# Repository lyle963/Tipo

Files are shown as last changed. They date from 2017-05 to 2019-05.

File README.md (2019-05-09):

# Tipo
Plug n Play Braille Keyboard for your smartphone

# What is available?
1. Arduino Firmware for a USB keyboard using atmega32u4
2. Eagle CAD board files to print the PCB

# TO-DO
1. Remove bt ezkey module and get the arduino micro to type stuff onto notepad using 2 or 3 buttons - Done

2. Repeat with USBOTG and make sure phone responds - Done

3. Connect 8 keys to micro on breadboard in matrix or parallel layout to verify all peri electronics - Done

4. Dump Leonardo bootloader to wild Atmega32u4 Chip - Done

5. Breadboard standalone chip with external oscillator,caps,resistors etc - Skipped like a bawz

6. Design / Fab pcb and test with phone - Done

7. CAD Case

8. Print case

9. Give board to visually impared peeps & get feedback

10. Brailler Trainer app

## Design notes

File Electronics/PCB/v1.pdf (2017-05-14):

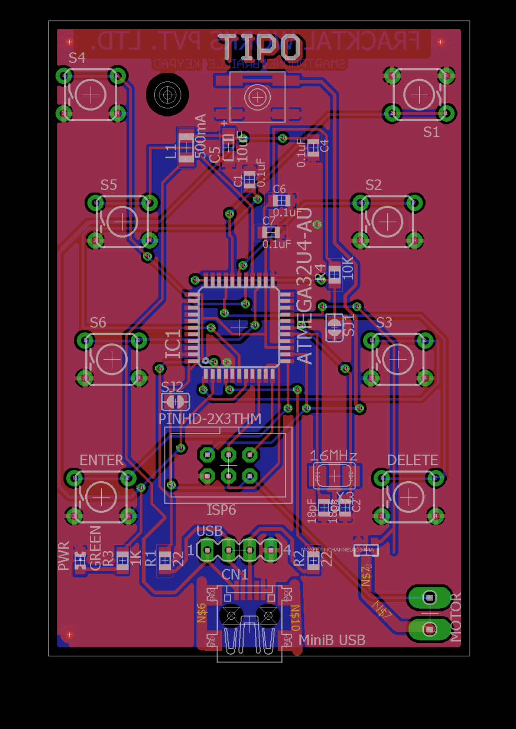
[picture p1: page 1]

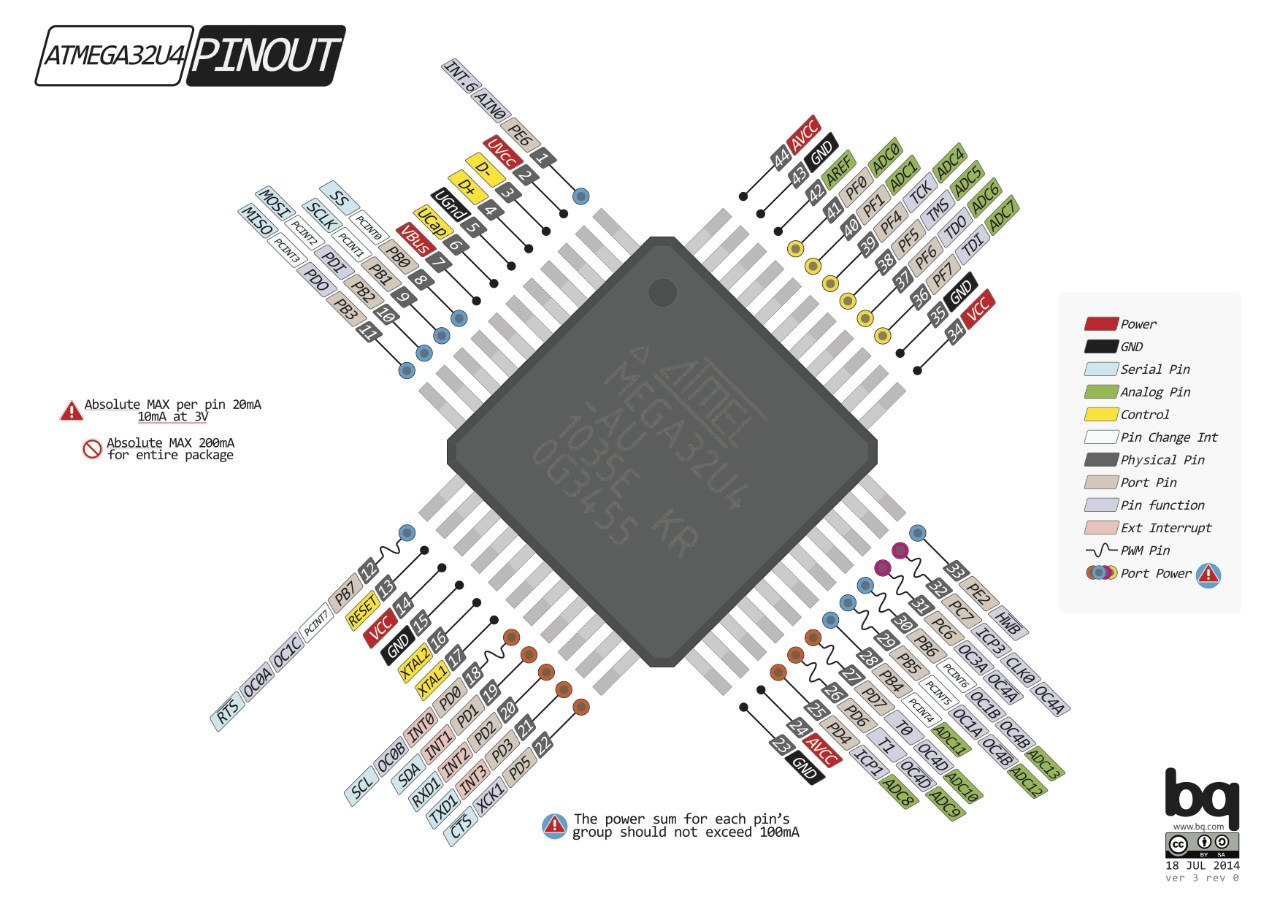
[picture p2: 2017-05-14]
Reference/pinout.jpg

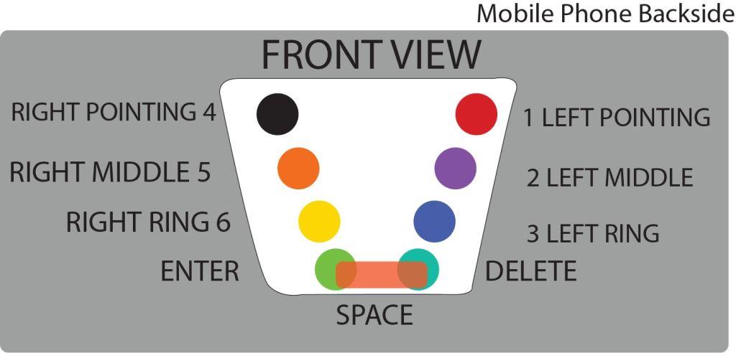
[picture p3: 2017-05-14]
Design/Layout.jpg

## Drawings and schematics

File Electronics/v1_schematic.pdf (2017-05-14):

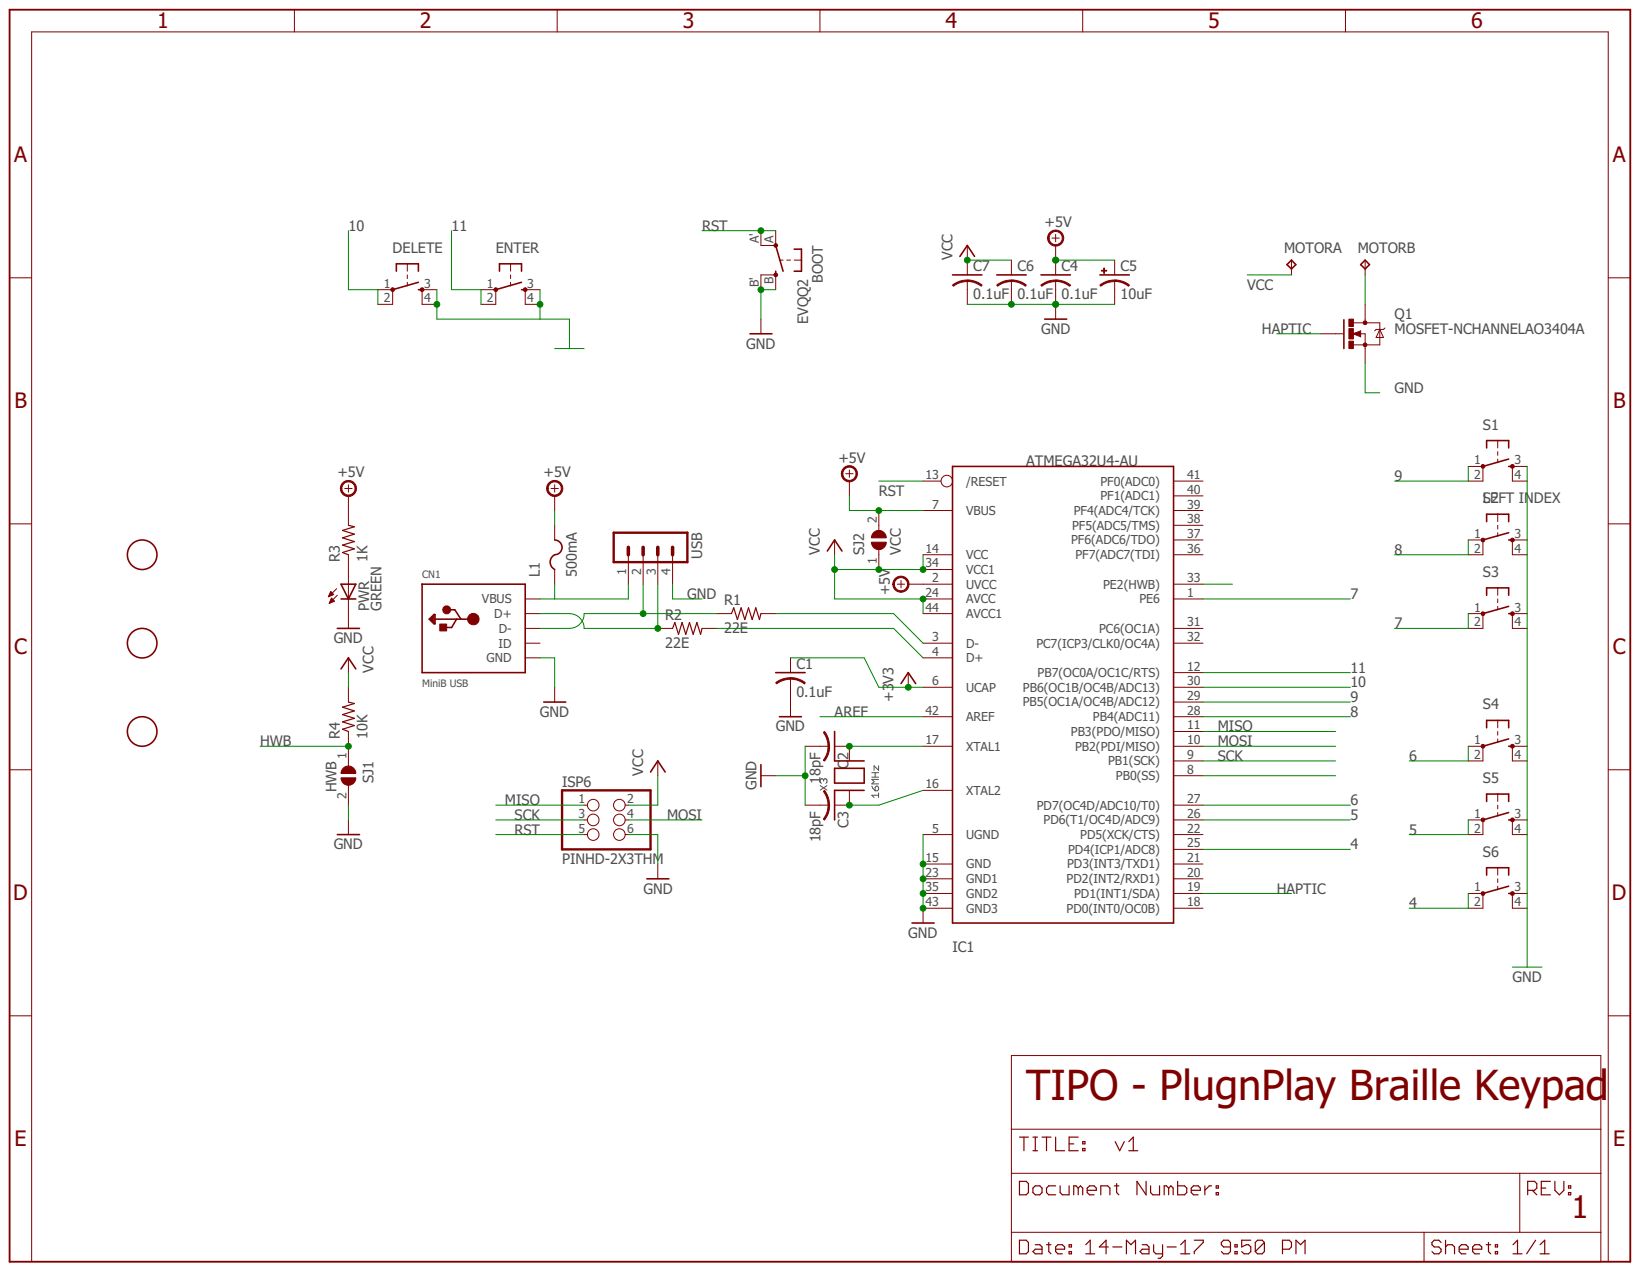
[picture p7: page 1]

TIPO - PlugnPlay Braille Keypad

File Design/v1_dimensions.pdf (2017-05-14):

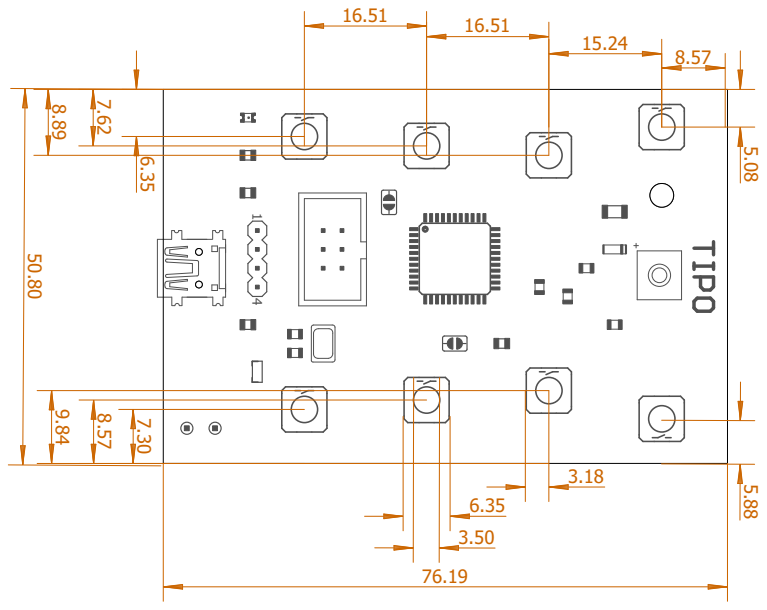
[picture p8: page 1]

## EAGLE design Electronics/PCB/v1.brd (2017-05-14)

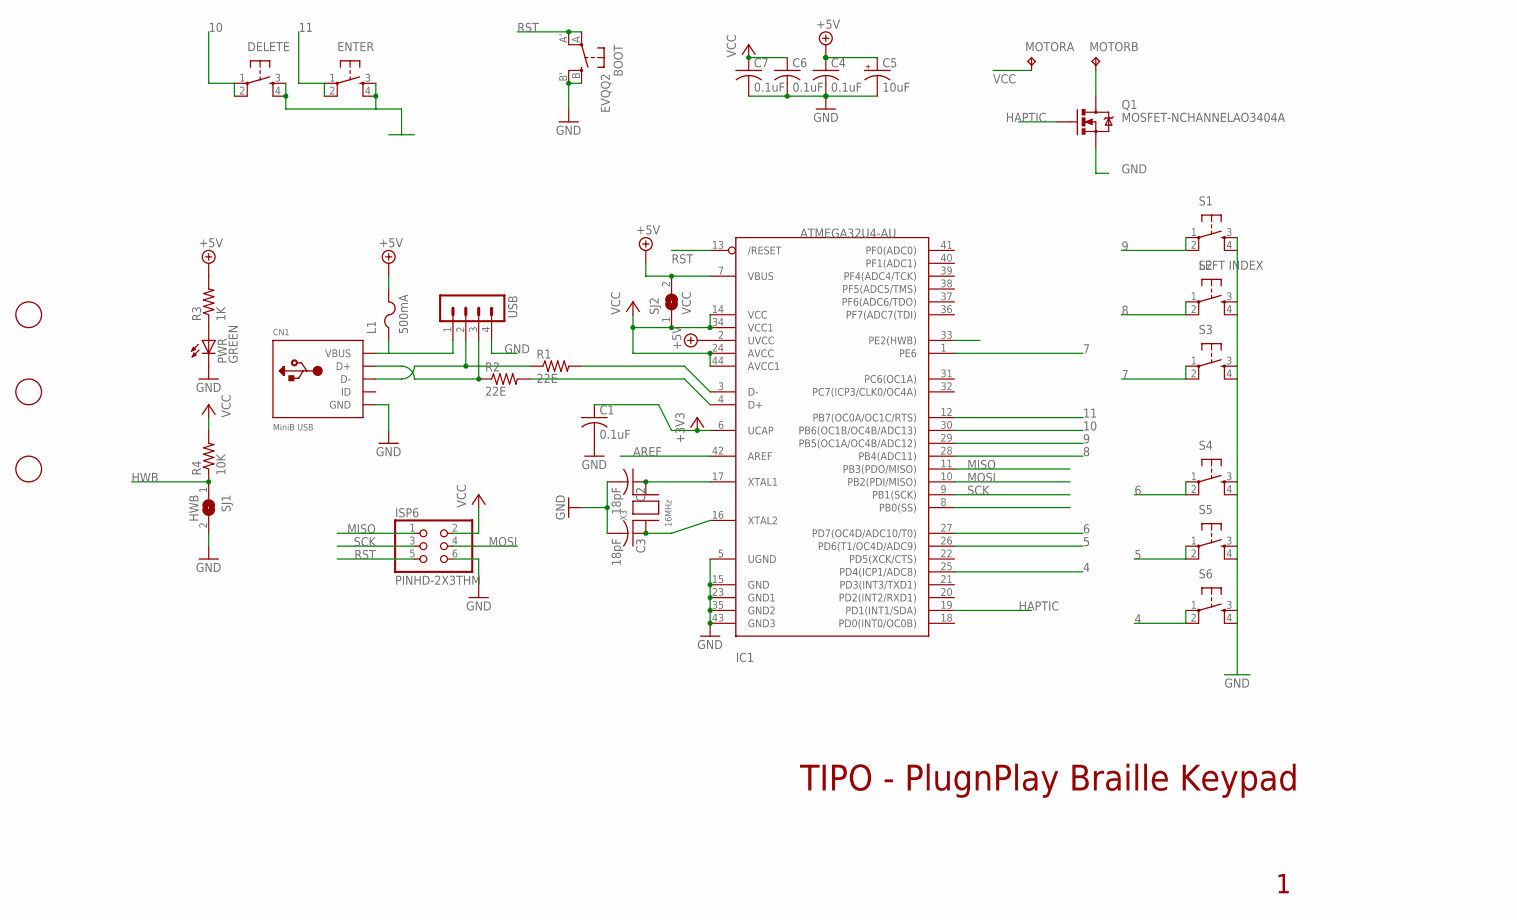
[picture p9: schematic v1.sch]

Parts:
BOOT: EVQQ2; EVQ-Q2
C1, C4, C6, C7: 0.1uF; C0805K
C2, C3: 18pF; C0805K
C5: 10uF; A/3216-18R
CN1: MiniB USB; USB-MINIB
DELETE: TAC_SWITCHPTH; TACTILE-PTH
ENTER: TAC_SWITCHPTH; TACTILE-PTH
IC1: ATMEGA32U4-AU; TQFP44
ISP6: PINHD-2X3THM; ISP6
L1: 500mA; R1206
MOTOR: TP2P2-38-17; P2-38-17
PWR: GREEN; CHIPLED_0805
Q1: MOSFET-NCHANNELAO3404A; SOT23-3
R1, R2: 22E; R0805
R3: 1K; R0805
R4: 10K; R0805
S1: LEFT INDEX; TACTILE-PTH
S2, S3, S4, S5, S6: TAC_SWITCHPTH; TACTILE-PTH
SJ1: HWB; SJ
SJ2: VCC; SJ
U$1, U$2, U$6: FIDUCIAL; FIDUCIAL_1MM
USB: MA04-1
X3: 16MHz; NX5032

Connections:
4: IC1.25 (PD4(ICP1/ADC8)), S6.1, S6.2
5: IC1.26 (PD6(T1/OC4D/ADC9)), S5.1, S5.2
6: IC1.27 (PD7(OC4D/ADC10/T0)), S4.1, S4.2
7: IC1.1 (PE6), S3.1, S3.2
8: IC1.28 (PB4(ADC11)), S2.1, S2.2
9: IC1.29 (PB5(OC1A/OC4B/ADC12)), S1.1, S1.2
10: DELETE.1, DELETE.2, IC1.30 (PB6(OC1B/OC4B/ADC13))
11: ENTER.1, ENTER.2, IC1.12 (PB7(OC0A/OC1C/RTS))
+3V3: C1.1, IC1.6 (UCAP)
+5V: C4.1, C5.+, IC1.2 (UVCC), IC1.7 (VBUS), L1.2, R3.2, SJ2.2
AREF: IC1.42 (AREF)
GND: BOOT.B (S), BOOT.B' (S1), C1.2, C2.2, C3.2, C4.2, C5.-, C6.2, C7.2, CN1.GND, DELETE.3, DELETE.4, ENTER.3, ENTER.4, IC1.5 (UGND), IC1.15 (GND), IC1.23 (GND1), IC1.35 (GND2), IC1.43 (GND3), ISP6.6, PWR.C, Q1.2 (S), S1.3, S1.4, S2.3, S2.4, S3.3, S3.4, S4.3, S4.4, S5.3, S5.4, S6.3, S6.4, SJ1.2, USB.4
HAPTIC: IC1.19 (PD1(INT1/SDA)), Q1.1 (G)
HWB: IC1.33 (PE2(HWB)), R4.1, SJ1.1
MISO: IC1.11 (PB3(PDO/MISO)), ISP6.1
MOSI: IC1.10 (PB2(PDI/MISO)), ISP6.4
unnamed: PWR.A, R3.1
unnamed: CN1.D+, R2.1, USB.3
unnamed: IC1.3 (D-), R1.2
unnamed: IC1.4 (D+), R2.2
unnamed: CN1.D-, R1.1, USB.2
unnamed: MOTOR.TP-2, Q1.3 (D)
unnamed: C2.1, IC1.17 (XTAL1), X3.P$2
unnamed: C3.1, IC1.16 (XTAL2), X3.P$1
PB0: IC1.8 (PB0(SS))
RST: BOOT.A, BOOT.A' (P1), IC1.13 (/RESET), ISP6.5
SCK: IC1.9 (PB1(SCK)), ISP6.3
VBUS: CN1.VBUS, L1.1, USB.1
VCC: C6.1, C7.1, IC1.14 (VCC), IC1.24 (AVCC), IC1.34 (VCC1), IC1.44 (AVCC1), ISP6.2, MOTOR.TP-1, R4.2, SJ2.1

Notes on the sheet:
TIPO - PlugnPlay Braille Keypad

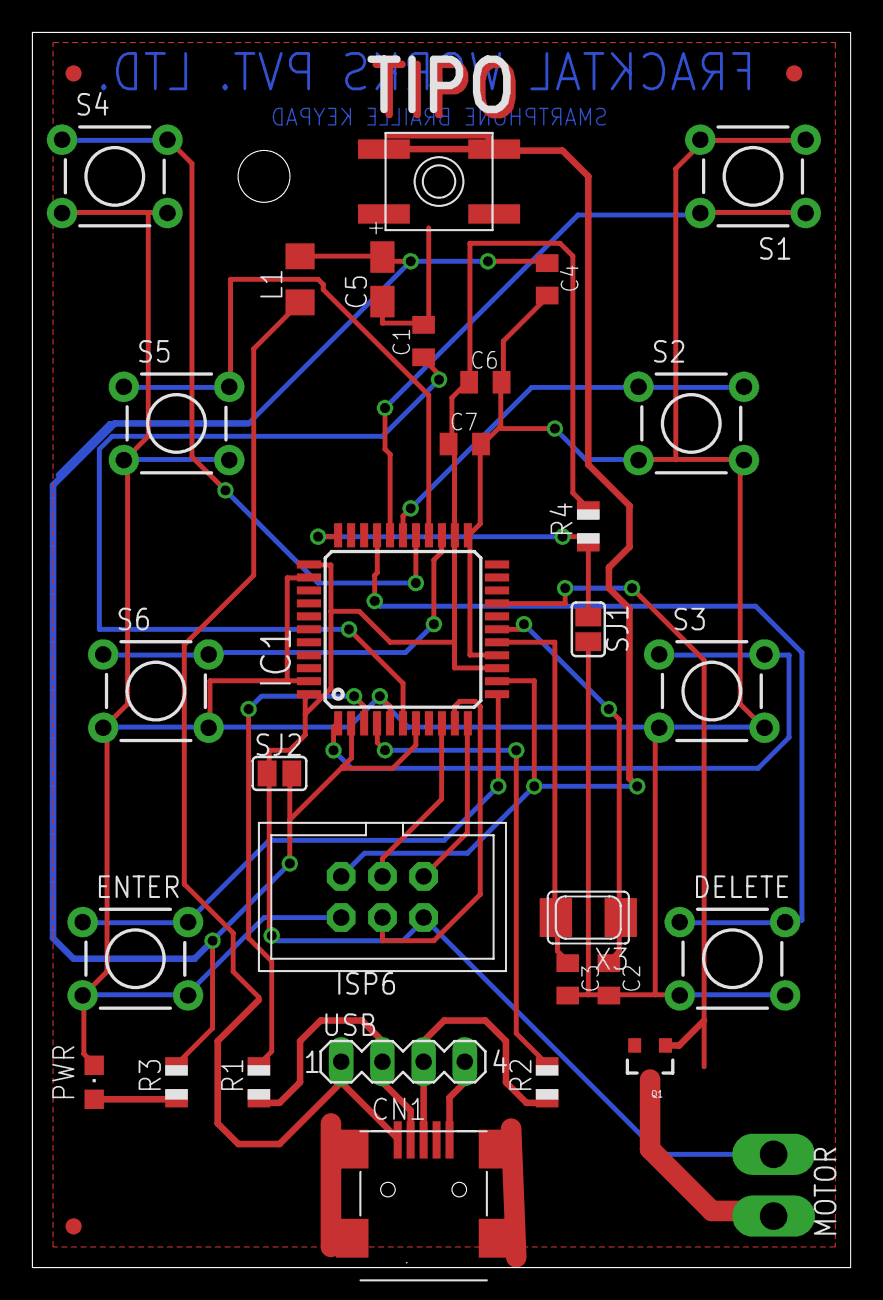
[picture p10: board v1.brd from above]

Board: 2 copper layers, 50.5 x 76.2 mm, 34 parts (0 on the bottom side), 27 nets.

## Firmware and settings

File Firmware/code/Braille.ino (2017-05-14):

#include "Keyboard.h"
#define mode usb
#define debug 1
#define bouncetime 50
enum modes {serial, usb};
bool newPress;
//               s6,s5,s4,s3,s2,s1,ENT,DEL
byte pinMap[] = {4 , 12, 6, 7, 8, 9, 11, 10 };
byte keyMap[] = {

  B000000,
  'A', B100000,//a
  'B', B110000,
  'C', B100100,
  'D', B100110,
  'E', B100010,
  'F', B110100,
  'G', B110110,
  'H', B110010,
  'I', B010100,
  'J', B010110,
  'K', B101000,
  'L', B111000,
  'M', B101100,
  'N', B101110,
  'O', B101010,
  'P', B111100,
  'Q', B111110,
  'R', B111010,
  'S', B011100,
  'T', B011110,
  'U', B101001,
  'V', B111001,
  'W', B010111,
  'X', B101101,
  'Y', B101111,
  'Z', B101011, //z
  '#', B001111,
};

void setup() {
  if (debug)
    Serial.begin(115200);
  if (mode == usb)
    Keyboard.begin();
  for (int i = 0; i <= 7; i++) {
    pinMode(pinMap[i], INPUT);
    digitalWrite(pinMap[i], HIGH);
  }
}

void loop() {
  char character = readKeys();

  if (newPress && character != 0) {
    if (mode == usb)
      Keyboard.print(character);
    else if (mode == serial)
      Serial.print(character);
    newPress = 0;
  }
  
  if (newPress) newPress = 0;
}

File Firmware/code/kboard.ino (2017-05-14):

char readKeys() {
  byte keys = waitForRelease();
  char c = convert(keys);
  if (debug)Serial.println(c);
  if (c != '#')
    return c;
  //handle numbers
  newPress = 0;
  keys = waitForRelease();
  c = convert(keys) - 16;//ascii conversion from A to 1, B to 2 etc
  if (c == 58) c = '0'; //0 after 9 not before 1 in braille alphabet
  if (debug)Serial.println(c);
  return c;

}



byte waitForRelease() {
  byte a = B000000;
  byte x = B000000;
  while (1) {
    x = 0;
    for (int i = 0; i < 6; i++) {
      if (digitalRead(pinMap[i]) == LOW) { //if button is GND then follow
        x = 1;
        x <<= i;
        a = a | x;
        delay(bouncetime);
        if (debug)Serial.println(a, BIN);
      }
    }
    if (a && !newPress)
      newPress = 1;
    if (!x && newPress)
    {
      delay(3* bouncetime);
      return a;
    }
    if (!a)
      FnKeys();
  }
}



void FnKeys() {
  byte buttons = 0; // B00(0) - nothing pressed, B01(1) - ent pressed, B10(2) - delete pressed, B11(3) - both pressed
  if (digitalRead(pinMap[6]) == LOW || digitalRead(pinMap[7]) == LOW) {
    delay(bouncetime/2);
    while(digitalRead(pinMap[6]) == LOW || digitalRead(pinMap[7]) == LOW){
      if (digitalRead(pinMap[6]) == LOW)
        buttons |= 1;
      if (digitalRead(pinMap[7]) == LOW)
        buttons |= 2;
    }
    if (mode == usb) {
      switch (buttons) {
        case 1:   Keyboard.press(KEY_RETURN);
          break;
        case 2:   Keyboard.press(KEY_BACKSPACE);
          break;
        case 3:   Keyboard.write(' ');
          break;
      }
      while (digitalRead(pinMap[7]) == LOW || digitalRead(pinMap[6]) == LOW);
      Keyboard.releaseAll();
      delay(bouncetime/2);
    }
    else if(mode == serial){
      Serial.print("FnButtons: ");
      Serial.println(buttons);
    }
  }
}


char convert(byte keys) {
  for (int i = 0; i <= 54; i += 2) {
    if (keyMap[i] == keys)
      return keyMap[i - 1];
  }
  return 0;
}

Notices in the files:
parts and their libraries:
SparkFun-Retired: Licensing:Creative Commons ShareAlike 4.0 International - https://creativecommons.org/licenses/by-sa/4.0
